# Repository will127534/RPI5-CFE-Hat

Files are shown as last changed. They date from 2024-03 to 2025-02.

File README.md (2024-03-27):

# CFexpress PCIe Hat for Raspberry Pi 5
Welcome to the GitHub repository for the open-source CFexpress (CFE) PCIe Hat designed specifically for the Raspberry Pi 5. This project aims to enhance the Raspberry Pi 5 by adding the ability to interface with CFexpress Type B cards directly, enabling high-speed data transfer and storage solutions.


## Features
* CFexpress Type B Card slot: Directly connect a CFexpress Type B card to your Raspberry Pi 5 for high-speed data storage and transfer.
* Automated Card Mounting: Utilizes a CH32V003 MCU for I2C to GPIO control, enabling the automated mounting and unmounting of the CFexpress card with the press of an eject button.
* QWIIC Hub: Includes a simple QWIIC hub that provides four additional QWIIC ports, allowing for easy expansion and connectivity with other QWIIC-compatible devices.
* Flexible Mounting Options: Designed to be mounted either on the top or the bottom of the Raspberry Pi 5. When mounted on top, the I2C connection is made directly from the GPIO header on the Raspberry Pi 5. For bottom mounting, the QWIIC port is used to connect and enable the auto-mount script.

## Notes
* Automounting feature requires I2C connection from either QWIIC port or RPI GPIO
* The board does not support hot-unplug even with the auto-mount script, so you will need to press the eject button to signal unmount request
* Gerber and CPL file for JLCPCB is under /Gerber
* [Interactive BOM](https://htmlpreview.github.io/?https://github.com/will127534/RPI5-CFE-Hat/blob/main/bom/ibom.html) [(provided by InteractiveHtmlBom)
](https://github.com/openscopeproject/InteractiveHtmlBom) and JLCPCB BOM under /bom
* Source Code for CH32V003 based I2C to GPIO and Python code on RPI under /software
* Limited amount on [Tindle](https://www.tindie.com/products/34094/) for sell

## Support
For questions, issues, or suggestions, please open an issue in the [GitHub repository](https://github.com/will127534/RPI5-CFE-Hat/issues)  
Also see [Quick Start Guide](https://github.com/will127534/RPI5-CFE-Hat/wiki/RPI5-CFE-Hat-Quick-Start-Guide)

## License
This project is licensed under the MIT License - see the LICENSE file for details.

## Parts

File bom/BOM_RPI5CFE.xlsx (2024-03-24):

Comment | Designator | Footprint | JLCPCB Part #（optional）
10uF | C1 | C_0805_2012Metric | C1952587
4.7uF | C11,C10 | C_0603_1608Metric | C389010
1nF | C4 | C_0402_1005Metric | C1523
10nF | C5 | C_0402_1005Metric | C15195
100nF | C6,C13,C7,C12 | C_0402_1005Metric | C131394
22uF | C8,C3,C2 | C_0805_2012Metric | C907991
100pF | C9 | C_0402_1005Metric | C445763
Blue | D2 | LED_0603_1608Metric | C72041
Yellow | D3 | LED_0603_1608Metric | C72038
Red | D4,D1 | LED_0603_1608Metric | C128249
Conn_01x16_Shielded | J1 | Hirose_FH12A-16S-0.5SH_1x16-1MP_P0.50mm_Horizontal | C597996
Conn_01x02_Shielded | J2 | JST_SH_SM02B-SRSS-TB_1x02-1MP_P1.00mm_Horizontal | C160402
101M-TE10 | J3 | 101M-TE10 | C17611134
Conn_01x04_Shielded | J9,J6,J7,J8,J4 | JST_SH_SM04B-SRSS-TB_1x04-1MP_P1.00mm_Horizontal | C160404
1.5uH | L1 | L_Vishay_IHLP-2020 | C845007
4.7K | R1 | R_0402_1005Metric | C140158
10K | R14 | R_0402_1005Metric | C144807
137K | R2 | R_0402_1005Metric | C102804
30K | R3 | R_0402_1005Metric | C352437
470R | R7,R6,R4,R5 | R_0402_1005Metric | C25117
SW_Push | SW1 | Panasonic_EVQPUM_EVQPUD | C388886
TPS564242DRLR | U1 | TPS564242DRLR_TEX | C5219267
CH32V003F4P6 | U2 | TSSOP-20_4.4x6.5mm_P0.65mm | C5187096
LP5907MFX-3.3 | U3 | SOT-23-5 | C80670
TCA9406DC | U4 | TCA9406DCUR | C840107

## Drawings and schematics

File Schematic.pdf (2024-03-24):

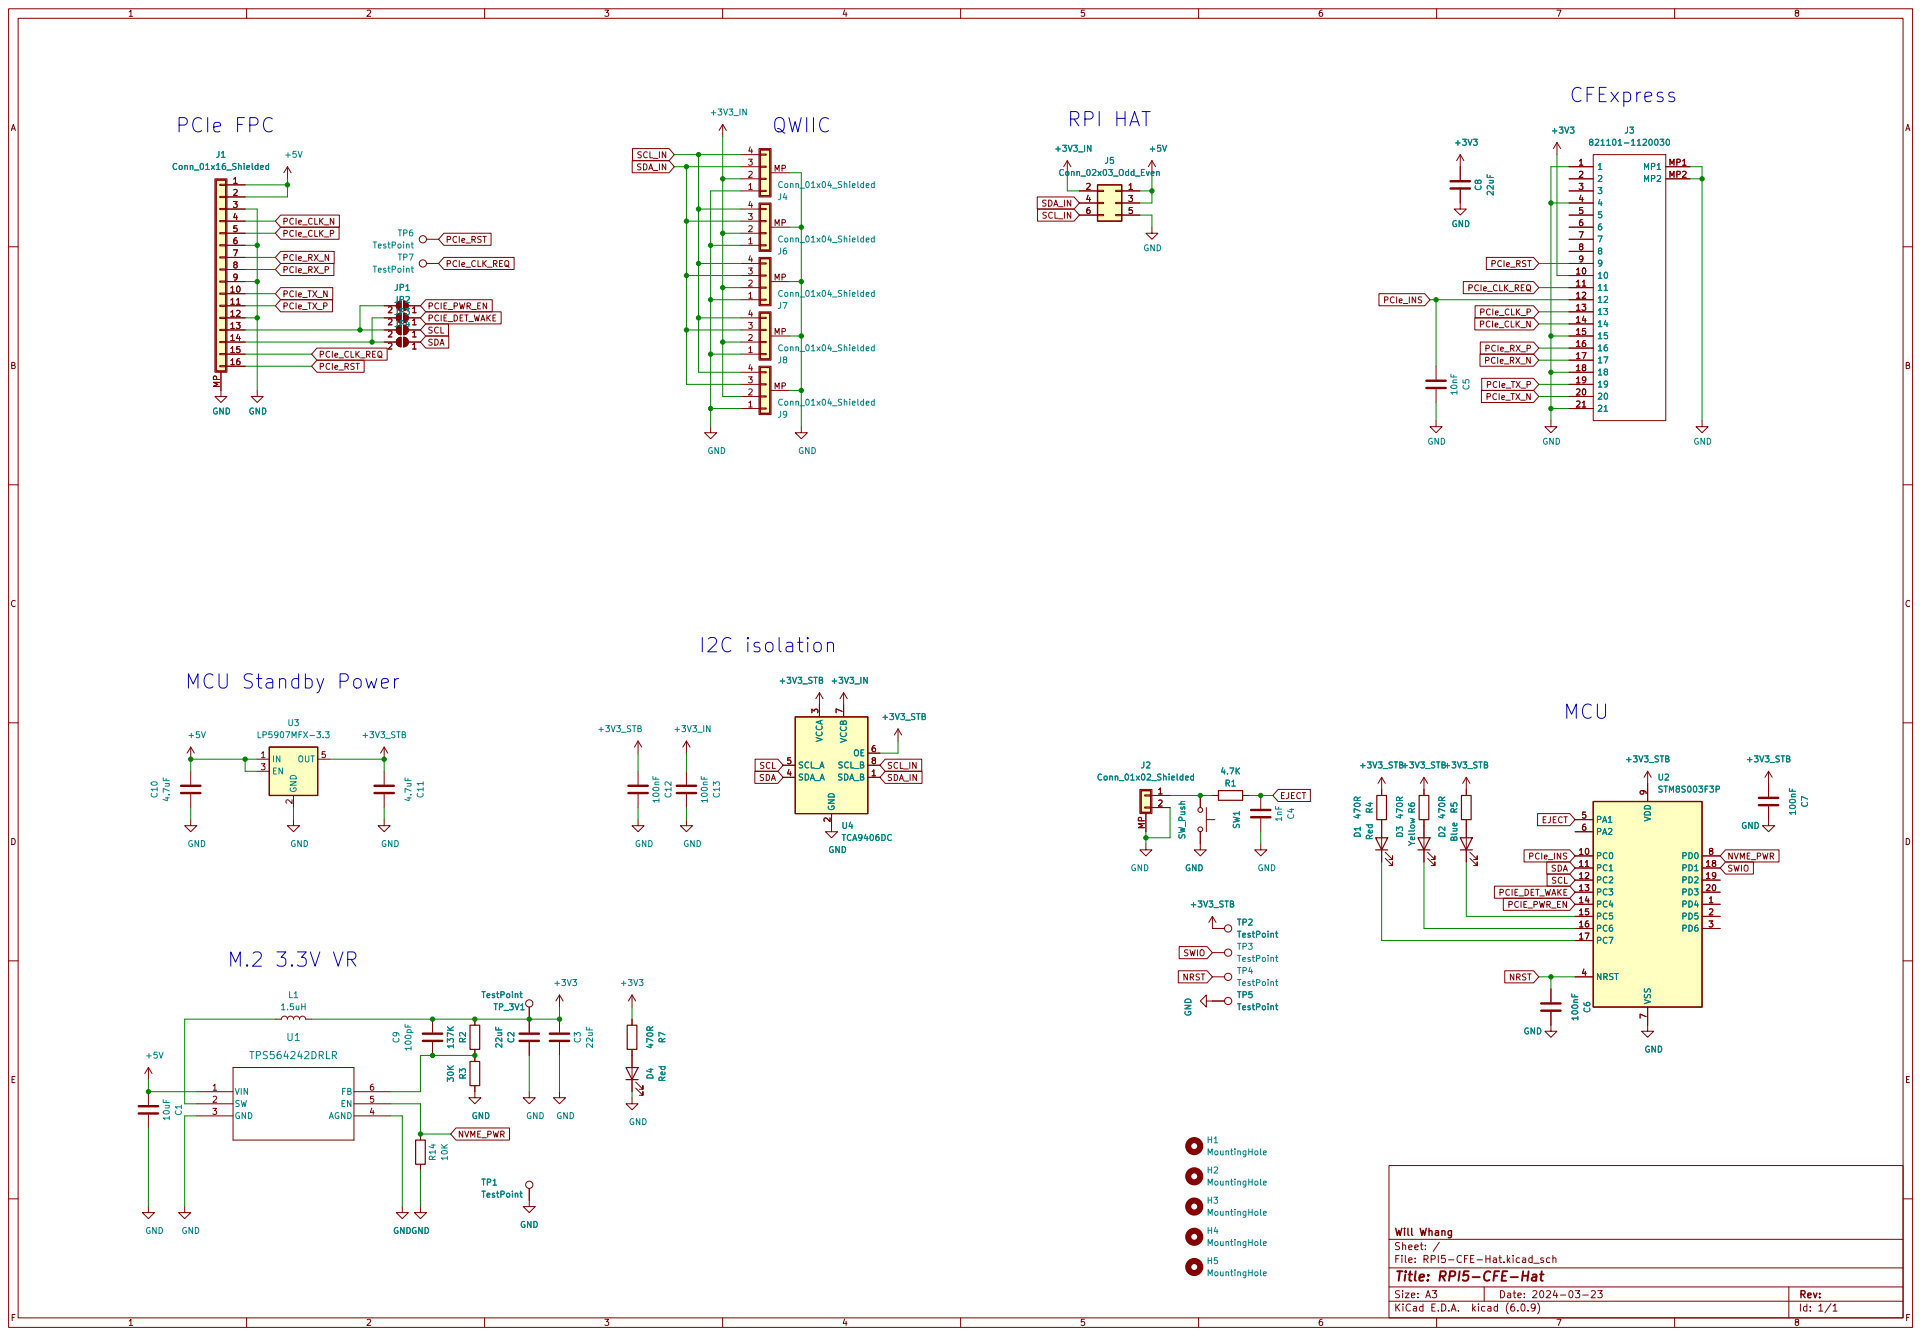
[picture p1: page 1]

File: RPI5-CFE-Hat.kicad_sch Sheet: / Will Whang GND

Id: 1/1 Title: RPI5-CFE-Hat

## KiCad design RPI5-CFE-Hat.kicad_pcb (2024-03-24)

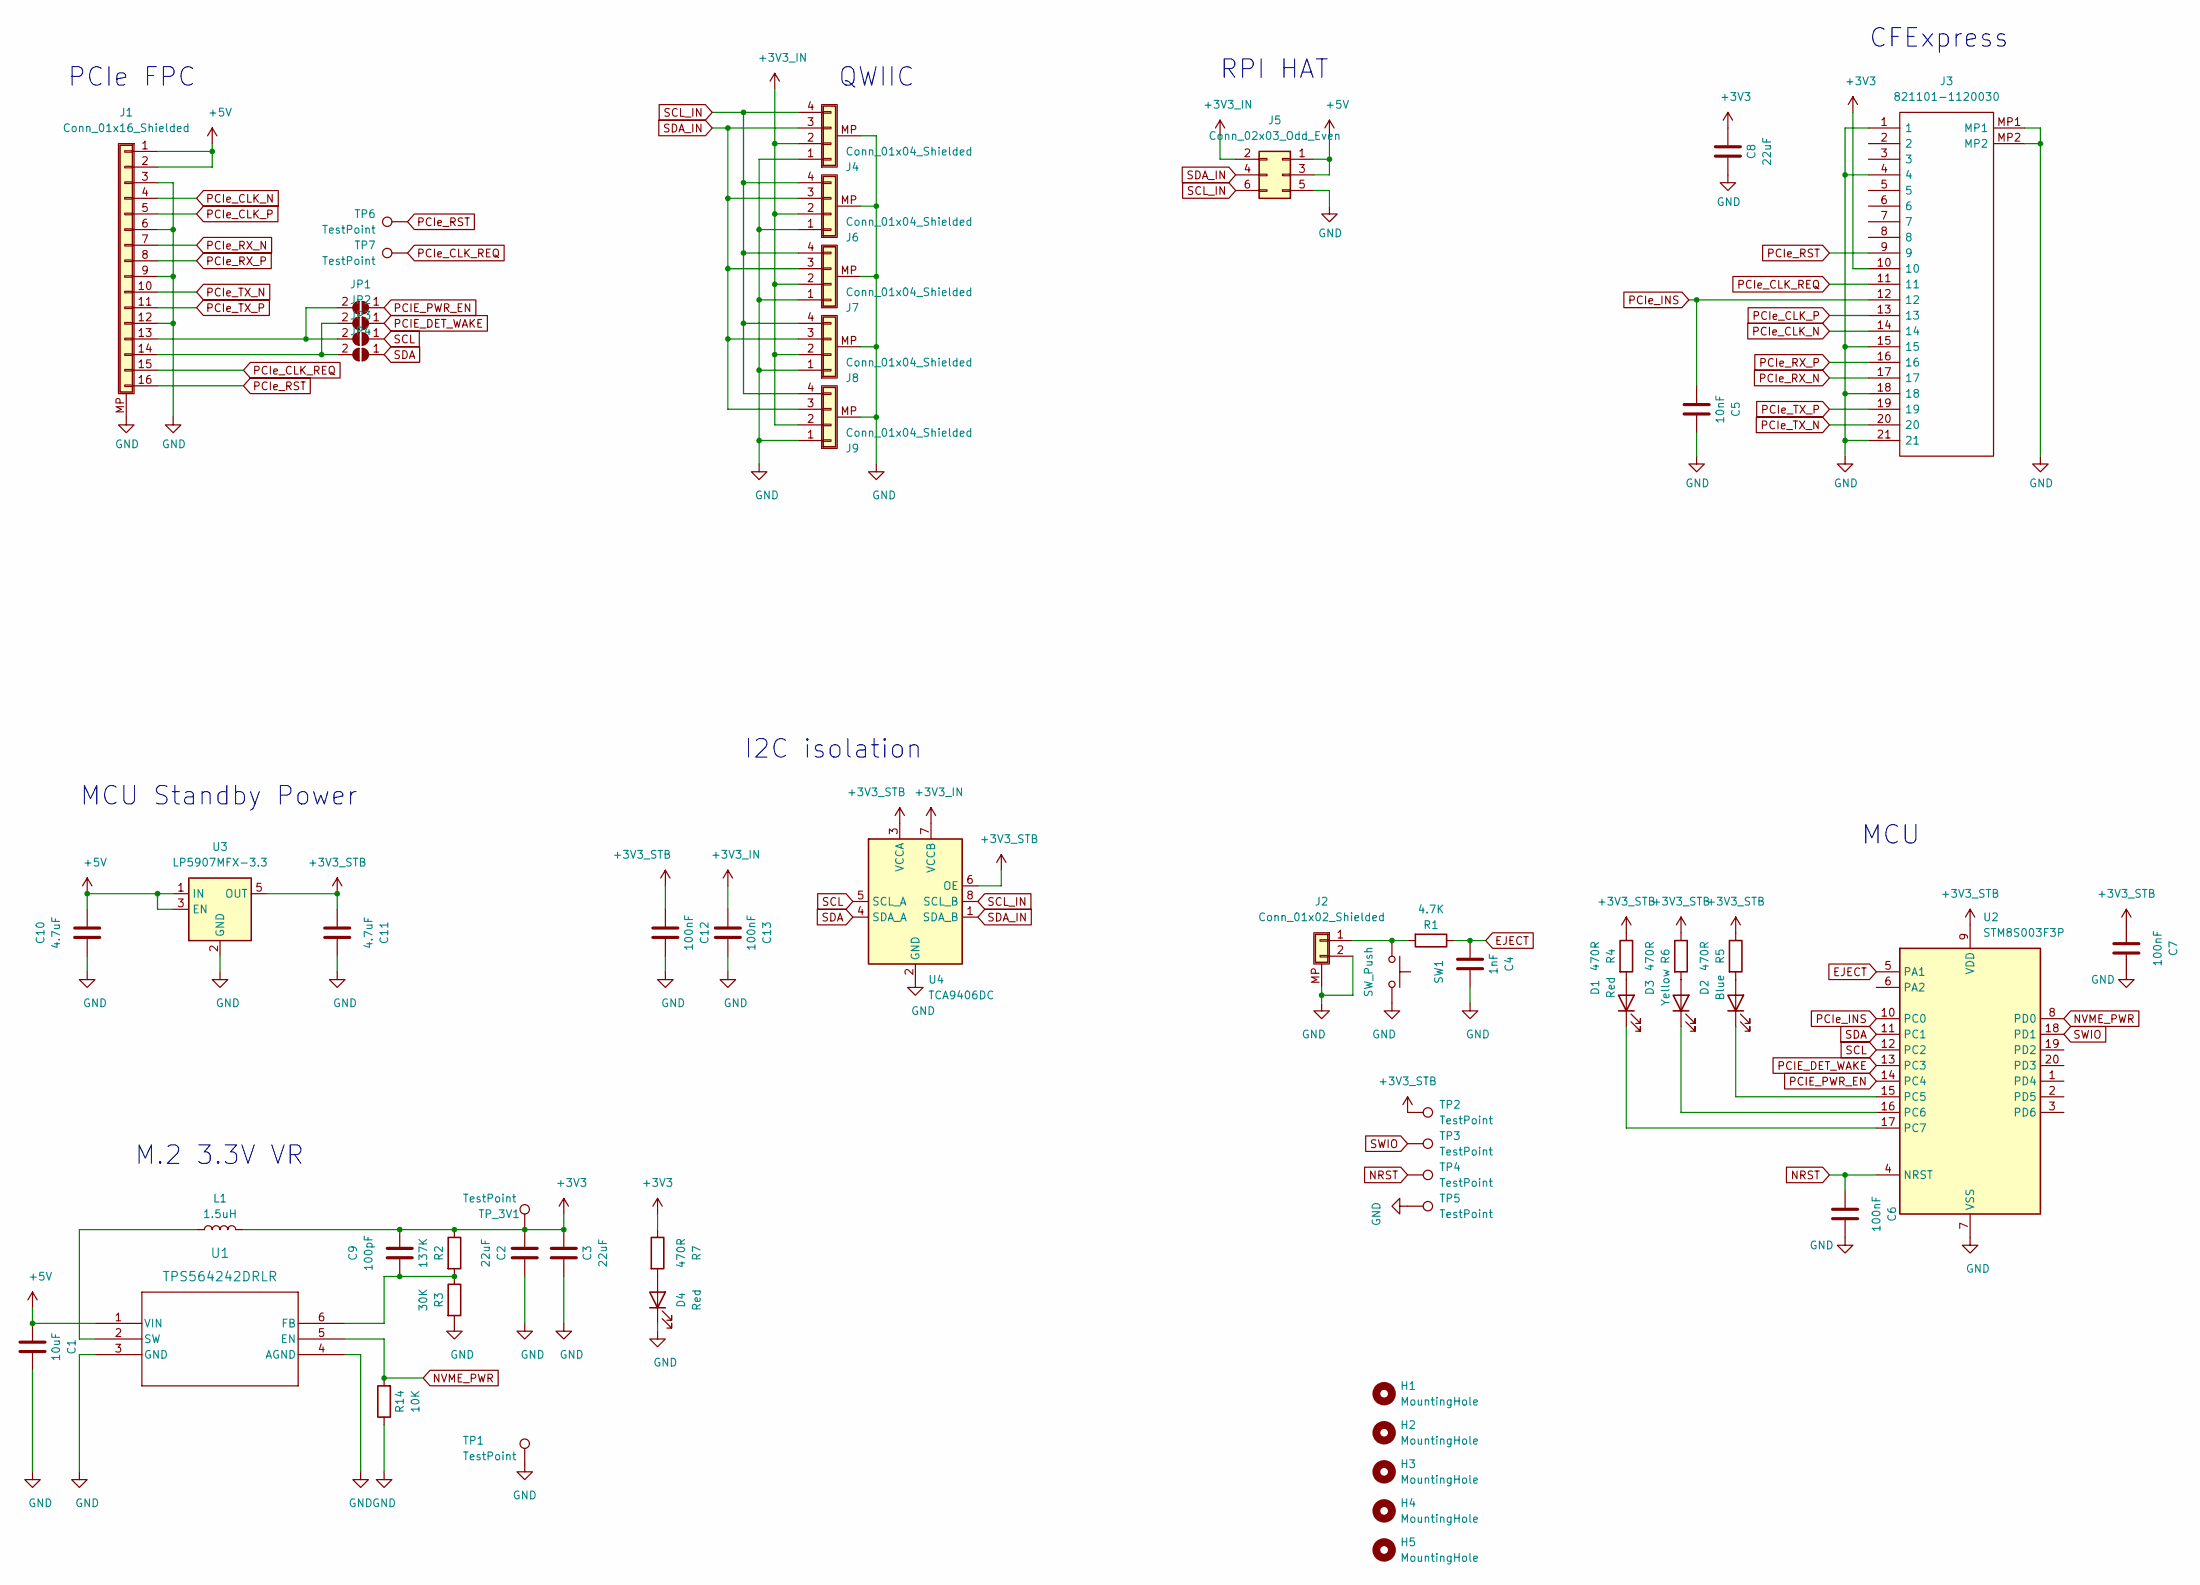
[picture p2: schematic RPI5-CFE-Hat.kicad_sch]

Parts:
C1: 10uF; C_0805_2012Metric
C2, C3, C8: 22uF; C_0805_2012Metric
C4: 1nF; C_0402_1005Metric
C5: 10nF; C_0402_1005Metric
C6, C7, C12, C13: 100nF; C_0402_1005Metric
C9: 100pF; C_0402_1005Metric
C10, C11: 4.7uF; C_0603_1608Metric
D1, D4: Red; LED_0603_1608Metric
D2: Blue; LED_0603_1608Metric
D3: Yellow; LED_0603_1608Metric
H1, H2, H3, H4, H5: MountingHole; MountingHole_2.7mm_M2.5
J1: Conn_01x16_Shielded; Hirose_FH12-16S-0.5SH_1x16-1MP_P0.50mm_Horizontal
J2: Conn_01x02_Shielded; JST_SH_SM02B-SRSS-TB_1x02-1MP_P1.00mm_Horizontal
J3: 821101-1120030; 8211011120030; Manufacturer_Part_Number 821101-1120030
J4, J6, J7, J8, J9: Conn_01x04_Shielded; JST_SH_SM04B-SRSS-TB_1x04-1MP_P1.00mm_Horizontal
J5: Conn_02x03_Odd_Even; PinSocket_2x03_P2.54mm_Vertical
JP1, JP2, JP3, JP4: SolderJumper_2_Open; SolderJumper-2_P1.3mm_Open_Pad1.0x1.5mm
L1: 1.5uH; L_Vishay_IHLP-2020
R1: 4.7K; R_0402_1005Metric
R2: 137K; R_0402_1005Metric
R3: 30K; R_0402_1005Metric
R4, R5, R6, R7: 470R; R_0402_1005Metric
R14: 10K; R_0402_1005Metric
SW1: SW_Push; Panasonic_EVQPUM_EVQPUD
TP1, TP2, TP3, TP4, TP5, TP6, TP7: TestPoint; TestPoint_Pad_D1.0mm
TP_3V1: TestPoint; TestPoint_Pad_D1.0mm
U1: TPS564242DRLR; TPS564242DRLR_TEX
U2: STM8S003F3P; TSSOP-20_4.4x6.5mm_P0.65mm
U3: LP5907MFX-3.3; SOT-23-5
U4: TCA9406DC; TCA9406DCUR

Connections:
+3V3: C2.1, C3.2, C8.2, C9.2, J3.10, L1.2, R2.1, R7.1, TP_3V1.1
+3V3_IN: C13.1, J4.2, J5.2, J6.2, J7.2, J8.2, J9.2, U4.7 (VCCB)
+3V3_STB: C7.1, C11.1, C12.1, R4.1, R5.1, R6.1, TP2.1, U2.9 (VDD), U3.5 (OUT), U4.3 (VCCA), U4.6 (OE)
+5V: C1.1, C10.2, J1.1, J1.2, J5.1, J5.3, U1.1 (VIN), U3.1 (IN), U3.3 (EN)
EJECT: C4.1, R1.1, U2.5 (PA1)
GND: C1.2, C2.2, C3.1, C4.2, C5.2, C6.2, C7.2, C8.1, C10.1, C11.2, C12.2, C13.2, D4.1 (K), J1.3, J1.6, J1.9, J1.12, J1.MP (Shield), J2.2, J2.MP (Shield), J3.1, J3.4, J3.15, J3.18, J3.21, J3.MP1, J3.MP2, J4.1, J4.MP (Shield), J5.5, J6.1, J6.MP (Shield), J7.1, J7.MP (Shield), J8.1, J8.MP (Shield), J9.1, J9.MP (Shield), R3.2, R14.1, SW1.1, TP1.1, TP5.1, U1.3 (GND), U1.4 (AGND), U2.7 (VSS), U3.2 (GND), U4.2 (GND)
NRST: C6.1, TP4.1, U2.4 (NRST)
NVME_PWR: R14.2, U1.5 (EN), U2.8 (PD0)
unnamed: C9.1, R2.2, R3.1, U1.6 (FB)
unnamed: D1.1 (K), U2.17 (PC7)
unnamed: D1.2 (A), R4.2
unnamed: D2.1 (K), U2.15 (PC5)
unnamed: D2.2 (A), R5.2
unnamed: D3.1 (K), U2.16 (PC6)
unnamed: D3.2 (A), R6.2
unnamed: D4.2 (A), R7.2
unnamed: J1.13, JP1.2 (B), JP3.2 (B)
unnamed: J1.14, JP2.2 (B), JP4.2 (B)
unnamed: J2.1, R1.2, SW1.2
unnamed: L1.1, U1.2 (SW)
PCIE_DET_WAKE: JP2.1 (A), U2.13 (PC3)
PCIE_PWR_EN: JP1.1 (A), U2.14 (PC4)
PCIe_CLK_N: J1.4, J3.14
PCIe_CLK_P: J1.5, J3.13
PCIe_CLK_REQ: J1.15, J3.11, TP7.1
PCIe_INS: C5.1, J3.12, U2.10 (PC0)
PCIe_RST: J1.16, J3.9, TP6.1
PCIe_RX_N: J1.7, J3.17
PCIe_RX_P: J1.8, J3.16
PCIe_TX_N: J1.10, J3.20
PCIe_TX_P: J1.11, J3.19
SCL: JP3.1 (A), U2.12 (PC2), U4.5 (SCL_A)
SCL_IN: J4.4, J5.6, J6.4, J7.4, J8.4, J9.4, U4.8 (SCL_B)
SDA: JP4.1 (A), U2.11 (PC1), U4.4 (SDA_A)
SDA_IN: J4.3, J5.4, J6.3, J7.3, J8.3, J9.3, U4.1 (SDA_B)
SWIO: TP3.1, U2.18 (PD1)

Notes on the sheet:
MCU
PCIe FPC
MCU Standby Power
QWIIC
I2C isolation
CFExpress
M.2 3.3V VR
RPI HAT

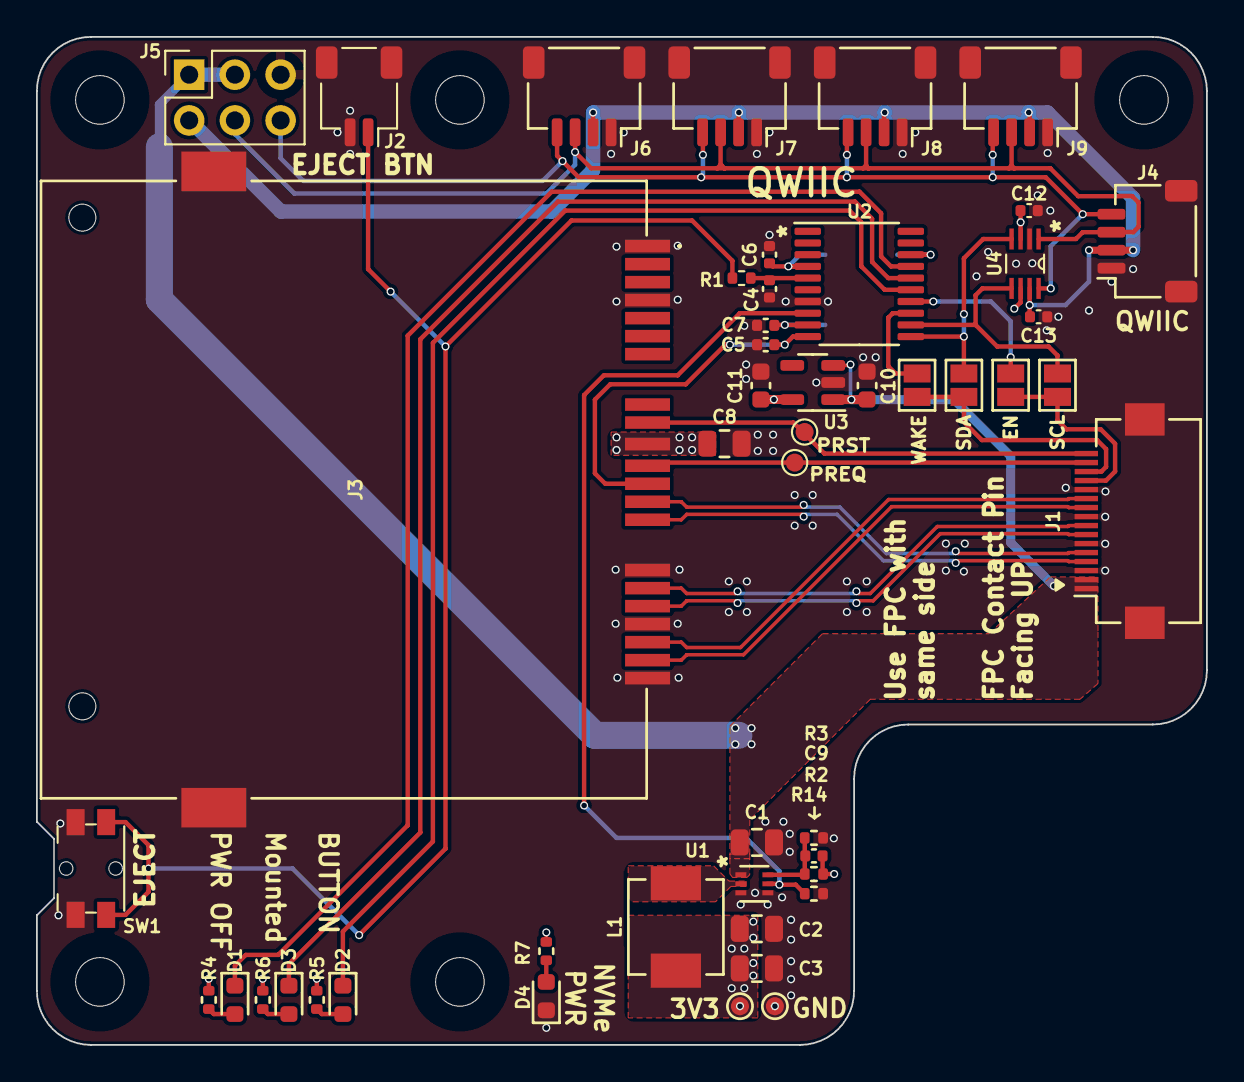
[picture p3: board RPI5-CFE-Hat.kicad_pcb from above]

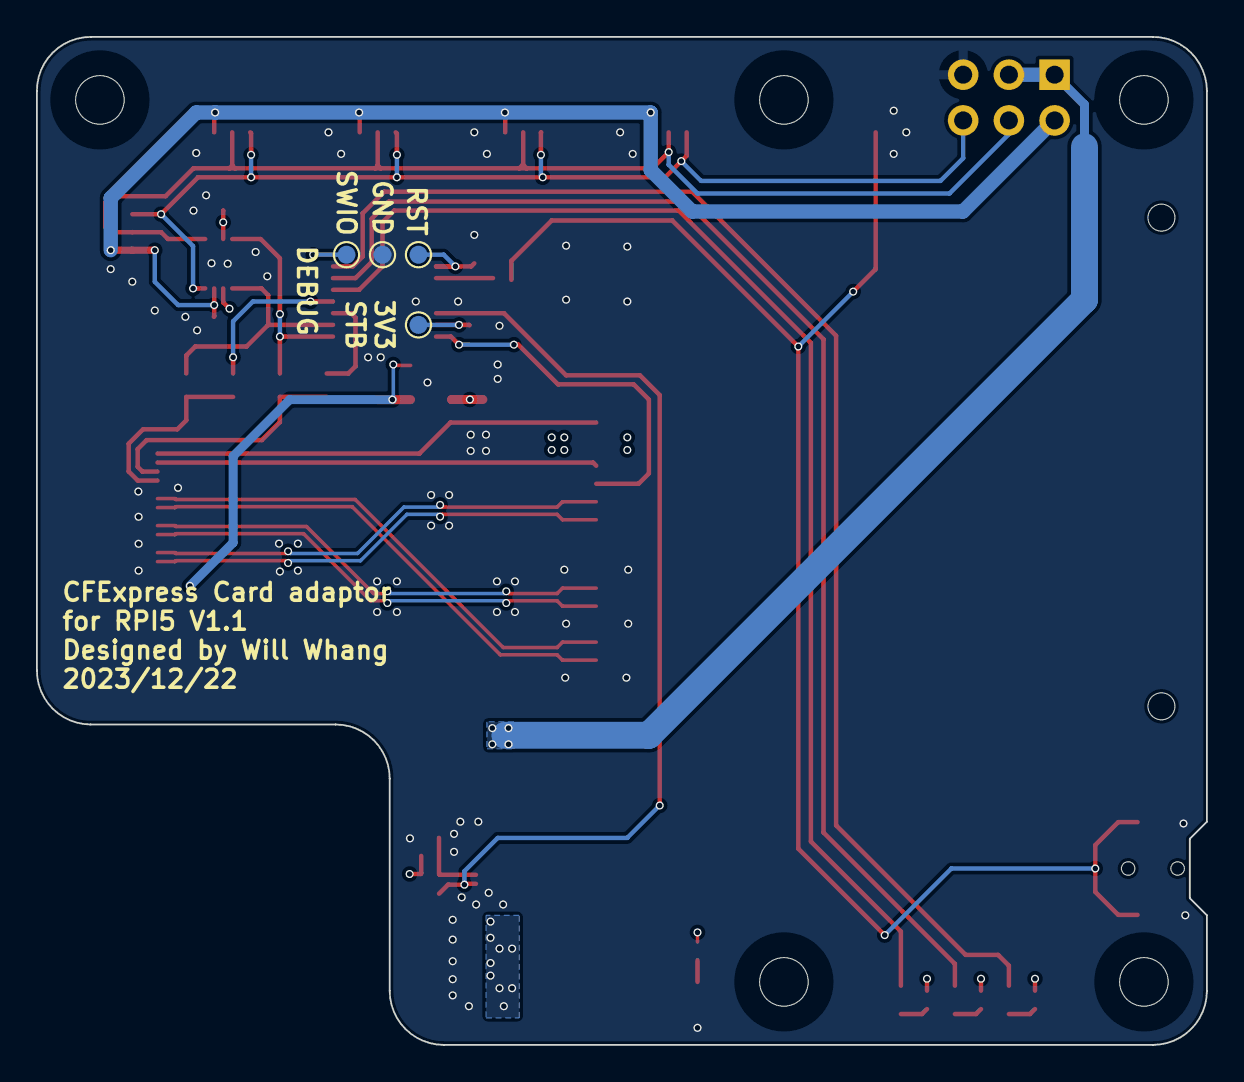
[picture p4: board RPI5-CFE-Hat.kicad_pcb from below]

Board: 4 copper layers, 65.0 x 56.0 mm, 57 parts (4 on the bottom side), 36 nets.

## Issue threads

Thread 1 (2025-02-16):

PCIE_WAKE issue on RPI5 16GB

schoolpost, 2025-02-16:
Having issue with NVME PWR not turning on when using CFE-Hat with Raspberry Pi 5 16GB. It will randomly work and enable sometimes, but 90% of the time it is not turning on.

will127534, 2025-02-18:
https://github.com/will127534/RPI5-CFE-Hat/blob/336090fc192560f209f878600cc7a5e767719ad5/Software/I2C_GPIO/User/main.c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

It looks like the pull-up in CH32V003 is not strong enough for the new RPI5 16GB board.../
This should change to push-pull and output high.

For the boards without FW update, a HW fix is to connect 3V3_STB testpoint on the back to the WAKE jumper pad on the top.

will127534, 2025-02-18:
Alright, update done in caa936fc69a23faab89d80574f4fa953d344324f

Closed 2025-02-18.

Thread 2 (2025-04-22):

RPI5 CFE Hat Designator L1 1.5uH or 4.7uH?

it5u, 2025-04-22:
In the RPI5 CFE Hat BOM file, the power inductance of Designator L1 is Comment 1.5uH, JLCPCB Part #C845007, The corresponding inductance value of IHLP2020CZER4R7M11 is 4.7uH. May I ask if a 1.5uH or 4.7uH inductor is used here? If it is 1.5uH, the corresponding inductance is IHLP2020CZER1R5M01, JLCPCB Part #C845001. Thank you!

it5u, 2025-04-22:
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

will127534, 2025-04-24:
4.7 uH inductor is used

it5u, 2025-04-24:
OK, Thank you!

it5u, 2025-04-24:
Okay, thank you for your product and response. Good luck!

李师军
***@***.***

Closed 2025-04-24.

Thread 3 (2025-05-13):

RPI5-CFE-Hat WAKE and EN welded issue

it5u, 2025-05-13:
What is the purpose of welding the two positions WAKE and EN respectively? Will there be any problems if they are not welded? Thanks!

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

will127534, 2025-05-14:
That is for reading the status from RPI's PCIe header to enable and notify the RPI the hat exists.

it5u, 2025-05-14:
Okay, it seems that I need to weld these two places myself. Thanks!

Closed 2025-05-14.

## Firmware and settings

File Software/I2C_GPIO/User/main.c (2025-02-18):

#include "debug.h"

/* I2C Communication Mode Selection */
//#define I2C_MODE   HOST_MODE
#define I2C_MODE   SLAVE_MODE

/* Global define */
#define Size   6
#define RXAdderss   0x34 << 1

/* Global Variable */
u8 direction = 0;
u32 currentStep = 0;
volatile  u8 TxData = 0;

/*********************************************************************
 * @fn      IIC_Init
 *
 * @brief   Initializes the IIC peripheral.
 *
 * @return  none
 */
void IIC_Init(u32 bound, u16 address)
{
    GPIO_InitTypeDef GPIO_InitStructure={0};
    I2C_InitTypeDef I2C_InitTSturcture={0};

    RCC_APB2PeriphClockCmd( RCC_APB2Periph_GPIOA | RCC_APB2Periph_GPIOD | RCC_APB2Periph_GPIOC | RCC_APB2Periph_AFIO, ENABLE );
    RCC_APB1PeriphClockCmd( RCC_APB1Periph_I2C1, ENABLE );

    //I2C
    GPIO_InitStructure.GPIO_Pin = GPIO_Pin_2;
    GPIO_InitStructure.GPIO_Mode = GPIO_Mode_AF_OD;
    GPIO_InitStructure.GPIO_Speed = GPIO_Speed_2MHz;
    GPIO_Init( GPIOC, &GPIO_InitStructure );

    GPIO_InitStructure.GPIO_Pin = GPIO_Pin_1;
    GPIO_InitStructure.GPIO_Mode = GPIO_Mode_AF_OD;
    GPIO_InitStructure.GPIO_Speed = GPIO_Speed_2MHz;
    GPIO_Init( GPIOC, &GPIO_InitStructure );

    //EJECT Button
    GPIO_InitStructure.GPIO_Pin = GPIO_Pin_1;
    GPIO_InitStructure.GPIO_Mode = GPIO_Mode_IPU;
    GPIO_InitStructure.GPIO_Speed = GPIO_Speed_2MHz;
    GPIO_Init( GPIOA, &GPIO_InitStructure );

    //CFE INSERT
    GPIO_InitStructure.GPIO_Pin = GPIO_Pin_0;
    GPIO_InitStructure.GPIO_Mode = GPIO_Mode_IPU;
    GPIO_InitStructure.GPIO_Speed = GPIO_Speed_50MHz;
    GPIO_Init( GPIOC, &GPIO_InitStructure );

    //RPI5 Control Signal
        //DET-WAKE
    GPIO_InitStructure.GPIO_Pin = GPIO_Pin_3;
    GPIO_InitStructure.GPIO_Mode = GPIO_Mode_Out_PP;
    GPIO_InitStructure.GPIO_Speed = GPIO_Speed_50MHz;
    GPIO_Init( GPIOC, &GPIO_InitStructure );
        //PWR_EN
    GPIO_InitStructure.GPIO_Pin = GPIO_Pin_4;
    GPIO_InitStructure.GPIO_Mode = GPIO_Mode_IPD;
    GPIO_InitStructure.GPIO_Speed = GPIO_Speed_50MHz;
    GPIO_Init( GPIOC, &GPIO_InitStructure );


    //LEDs
    GPIO_InitStructure.GPIO_Pin = GPIO_Pin_5;
    GPIO_InitStructure.GPIO_Mode = GPIO_Mode_Out_PP;
    GPIO_InitStructure.GPIO_Speed = GPIO_Speed_50MHz;
    GPIO_Init( GPIOC, &GPIO_InitStructure );

    GPIO_InitStructure.GPIO_Pin = GPIO_Pin_6;
    GPIO_InitStructure.GPIO_Mode = GPIO_Mode_Out_PP;
    GPIO_InitStructure.GPIO_Speed = GPIO_Speed_50MHz;
    GPIO_Init( GPIOC, &GPIO_InitStructure );

    GPIO_InitStructure.GPIO_Pin = GPIO_Pin_7;
    GPIO_InitStructure.GPIO_Mode = GPIO_Mode_Out_PP;
    GPIO_InitStructure.GPIO_Speed = GPIO_Speed_50MHz;
    GPIO_Init( GPIOC, &GPIO_InitStructure );


    //NVME PWR
    GPIO_InitStructure.GPIO_Pin = GPIO_Pin_0;
    GPIO_InitStructure.GPIO_Mode = GPIO_Mode_Out_PP;
    GPIO_InitStructure.GPIO_Speed = GPIO_Speed_50MHz;
    GPIO_Init( GPIOD, &GPIO_InitStructure );


    I2C_InitTSturcture.I2C_ClockSpeed = bound;
    I2C_InitTSturcture.I2C_Mode = I2C_Mode_I2C;
    I2C_InitTSturcture.I2C_DutyCycle = I2C_DutyCycle_16_9;
    I2C_InitTSturcture.I2C_OwnAddress1 = address;
    I2C_InitTSturcture.I2C_Ack = I2C_Ack_Enable;
    I2C_InitTSturcture.I2C_AcknowledgedAddress = I2C_AcknowledgedAddress_7bit;
    I2C_Init( I2C1, &I2C_InitTSturcture );

    I2C_Cmd( I2C1, ENABLE );


    I2C_StretchClockCmd( I2C1, DISABLE );

    // Enable interrupts
    I2C1->CTLR2 |= I2C_CTLR2_ITBUFEN;
    I2C1->CTLR2 |= I2C_CTLR2_ITEVTEN; // Event interrupt
    I2C1->CTLR2 |= I2C_CTLR2_ITERREN; // Error interrupt

    NVIC_EnableIRQ(I2C1_EV_IRQn); // Event interrupt
    NVIC_SetPriority(I2C1_EV_IRQn, 2 << 4);
    NVIC_EnableIRQ(I2C1_ER_IRQn); // Error interrupt



}

/*********************************************************************
 * @fn      main
 *
 * @brief   Main program.
 *
 * @return  none
 */

#define LED_GPIO GPIOC
#define LEDG GPIO_Pin_5
#define LEDB GPIO_Pin_6
#define LEDR GPIO_Pin_7



#define NVME_PWR_GPIO GPIOD
#define NVME_PWR GPIO_Pin_0

#define CTRL_GPIO GPIOC
#define DET_WAKE GPIO_Pin_3
#define PWR_EN GPIO_Pin_4
#define INSERT GPIO_Pin_0

#define BUTTON_GPIO GPIOA
#define BUTTON GPIO_Pin_1

int main(void)
{
    Delay_Init();

    IIC_Init( 400000, RXAdderss);
    GPIO_WriteBit(LED_GPIO, LEDR, 0);
    GPIO_WriteBit(LED_GPIO, LEDG, 1);
    GPIO_WriteBit(LED_GPIO, LEDB, 1);

    GPIO_WriteBit(NVME_PWR_GPIO, NVME_PWR, 0);

    GPIO_WriteBit(CTRL_GPIO, DET_WAKE, 1);
    //Delay_Ms(1000);
    while (1){
        TxData = GPIO_ReadInputDataBit(CTRL_GPIO, INSERT) | (GPIO_ReadInputDataBit(BUTTON_GPIO, BUTTON) << 1);
        GPIO_WriteBit(LED_GPIO, LEDG, TxData & 0x02);
        if (GPIO_ReadInputDataBit(CTRL_GPIO, PWR_EN)) {
            GPIO_WriteBit(NVME_PWR_GPIO, NVME_PWR, 1);
            GPIO_WriteBit(LED_GPIO, LEDR, 1);
        }
        else{
            GPIO_WriteBit(NVME_PWR_GPIO, NVME_PWR, 0);
            GPIO_WriteBit(LED_GPIO, LEDR, 0);
            GPIO_WriteBit(LED_GPIO, LEDB, 1);
        }

    }
}




void I2C1_EV_IRQHandler(void) __attribute__((interrupt));
void I2C1_EV_IRQHandler(void) {
    uint16_t STAR1, STAR2 __attribute__((unused));
    STAR1 = I2C1->STAR1;
    STAR2 = I2C1->STAR2;

    //GPIO_WriteBit(LED_GPIO, LEDB, 0);
    I2C1->CTLR1 |= I2C_CTLR1_ACK;

    if (STAR1 & I2C_STAR1_RXNE) { // Write event
        GPIO_WriteBit(LED_GPIO, LEDB, !(I2C1->DATAR == 0x01));
    }
    if (STAR1 & I2C_STAR1_TXE) { // Read event
        I2C1->DATAR = TxData;
    }
    //GPIO_WriteBit(LED_GPIO, LEDB, 1);
}

void I2C1_ER_IRQHandler(void) __attribute__((interrupt));
void I2C1_ER_IRQHandler(void) {
    uint16_t STAR1 = I2C1->STAR1;

    if (STAR1 & I2C_STAR1_BERR) { // Bus error
        I2C1->STAR1 &= ~(I2C_STAR1_BERR); // Clear error
    }

    if (STAR1 & I2C_STAR1_ARLO) { // Arbitration lost error
        I2C1->STAR1 &= ~(I2C_STAR1_ARLO); // Clear error
    }

    if (STAR1 & I2C_STAR1_AF) { // Acknowledge failure
        I2C1->STAR1 &= ~(I2C_STAR1_AF); // Clear error
    }
}
